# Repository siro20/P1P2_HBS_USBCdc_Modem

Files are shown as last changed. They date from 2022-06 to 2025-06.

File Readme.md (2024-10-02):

# Daikin P1/P2 Raspberry Pi hat

This project is about a Raspberry Pi hat/standalone interface to communicate
over the proprietary Daikin P1/P2 power-line bus.

Instead of a [MAX22088](https://www.analog.com/en/products/max22088.html)
it uses a [Raspberry Pi Pico](https://www.raspberrypi.com/products/raspberry-pi-pico/)
and [LM4871](https://www.ti.com/product/LM4871) audio amplifier as modem.

For more details on P1/P2 bus check out
[https://github.com/Arnold-n/P1P2Serial](https://github.com/Arnold-n/P1P2Serial).

It features:
- Galvanic isolation
- 115200baud ASCII [UART interface](pico/doc/uart.md)
- [3 Status LEDs](pico/doc/leds.md)
- Autonomous mode to emulate "External controller" on address F0h
- Bus idle/busy detection
- Collision detection on TX
- Easy to solder: [no QFN parts, only SOIC-8](kicad/doc/circuits.md)
- Cost around 20€ (PCB + parts)
- Raspberry Pi hat compatible (powered from +5V)
- Micro-USB for standalone mode (powered over USB)

The board can be powered over Micro-USB only and doesn't need a Raspberry Pi
baseboard. The communication then will be done over the virtual USB UART.

    This project is not an offical Daikin product. Use own your own risk!
    It has been tested on a Daikin EJHA04AAV3.

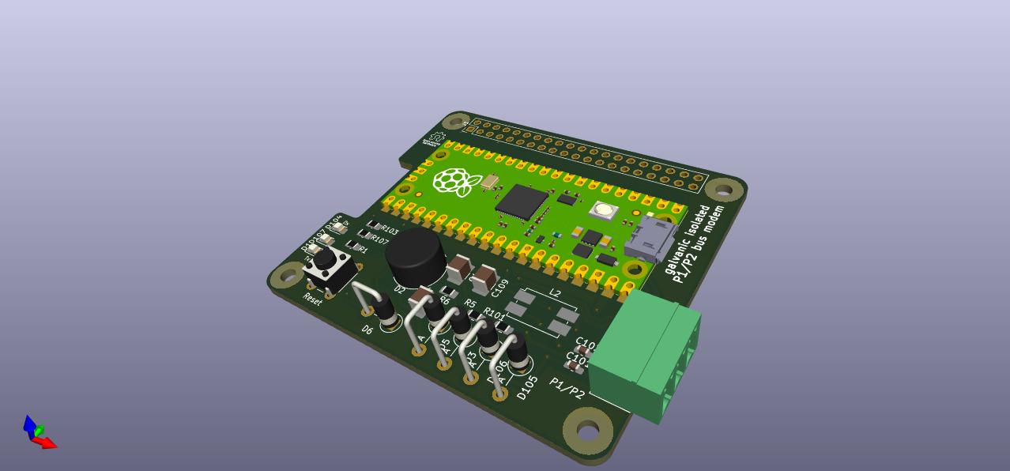
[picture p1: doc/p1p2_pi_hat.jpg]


## Chapters

- [User handbook](doc/handbook.md)
- [The electronics in detail](kicad/doc/circuits.md)
- [Ti LM4871 vs STM TS4990](kicad/doc/clicks.md)
- [Emulating a differential ADC](pico/doc/ADC.md)
- [Protocol used by the UART](pico/doc/uart.md)
- [Decoding the LED status](pico/doc/leds.md)
- [Hardware off-load the P1/P2 encoding using PIO0](pico/doc/Pio0.md)
- [Hardware off-load inversing ADC channel1](pico/doc/Pio1.md)

## Sources

- The hardware can be found here: [kicad](./kicad)
- The software can be found here: [pico](./pico)
- The host software can be found here: [siro20/P1P2decoder](https://github.com/siro20/P1P2decoder)

## The hardware

There are 3 connectors on the Pi hat:
1. Rasperry Pi 40-pin header
   - Provides power
   - Connects to the UART on GPIO14/GPIO15
   - Connects CTS/RTS on GPIO16/GPIO17
   - Signals a bus collision on GPIO22
2. P1/P2 bus connector
   - P1
   - P2
   - Earth
3. Micro USB
   - Allows to update the Pico firmware
   - Powers the board when used in standalone mode
   - Optional when using the 40-pin header

Buttons:
   - A. Reset button
   - B. Boot-mode button

      Hold button B and press button A to enter the Raspberry Pico USB bootloader.

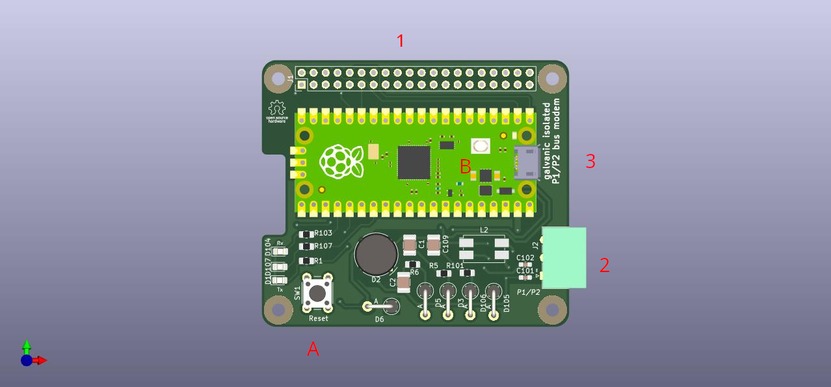
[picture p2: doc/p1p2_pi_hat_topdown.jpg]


## Disclaimer

    THE OPEN SOURCE SOFTWARE/HARDWARE IN THIS PROJECT IS DISTRIBUTED
    IN THE HOPE THAT IT WILL BE USEFUL, BUT WITHOUT ANY WARRANTY, WITHOUT
    EVEN THE IMPLIED WARRANTY OF MERCHANTABILITY OR FITNESS FOR A
    PARTICULAR PURPOSE.

    The "Daikin P1/P2 Raspberry Pi hat" has been designed and tested with
    Daikin's P1/P2 bus. You must not use this project to interface any
    other electrical bus.

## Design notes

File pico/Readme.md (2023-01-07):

# RPI PICO P1/P2 modem source code

This project aims to access the 2-wire interface on Daikin heap pump systems called P1/P2.
It's inspired by [Arnold-n/P1P2Serial](https://github.com/Arnold-n/P1P2Serial), but builds
on a RPI hat using the RPI PICO as P1/P2 modem.

## Design

The modem uses ADC Chan1/Chan2 in round robin mode for RX and PIO0 for TX.

While the TX part needs no CPU cycles (except pushing to the PIO TX FIFO), the
RX path occupies the whole Cortex-M0+ CPU core.

## Build instructions

The code makes use of the [pico-sdk](https://github.com/raspberrypi/pico-sdk).
It's linked as submodule so you need to check it out first:

```
cd pico
git submodule update --init --checkout --recursive
cmake .
make
```

It generates an U2F file in `pico/src/p1p2.uf2` that can be copied to the
USB mass storage devices emulated by the Pico.

### Stats TX
- 16x Oversampling on TX

### Stats RX
- 32x Differential oversampling on RX providing 9bit
- 7-step FIR filter
- Resampler after FIR to 16x Oversampling
- P1/P2 decoder detecting parity, frame and polarity errors

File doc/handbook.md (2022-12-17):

# User handbook

The "Daikin P1/P2 Raspberry Pi hat" can operate in two modes:
1. Standalone
2. RPi hat

In **Standalone mode** the board is powered over USB and the communication
is done over USB CDC.

In **RPi hat mode** the board is connected to a Raspberry Pi using the
40pin connector. You can optionally connect the USB cable, but ito's only
needed for updating the firmware using DCU mode. For normal operation the
USB cable is not required.



### Standalone mode

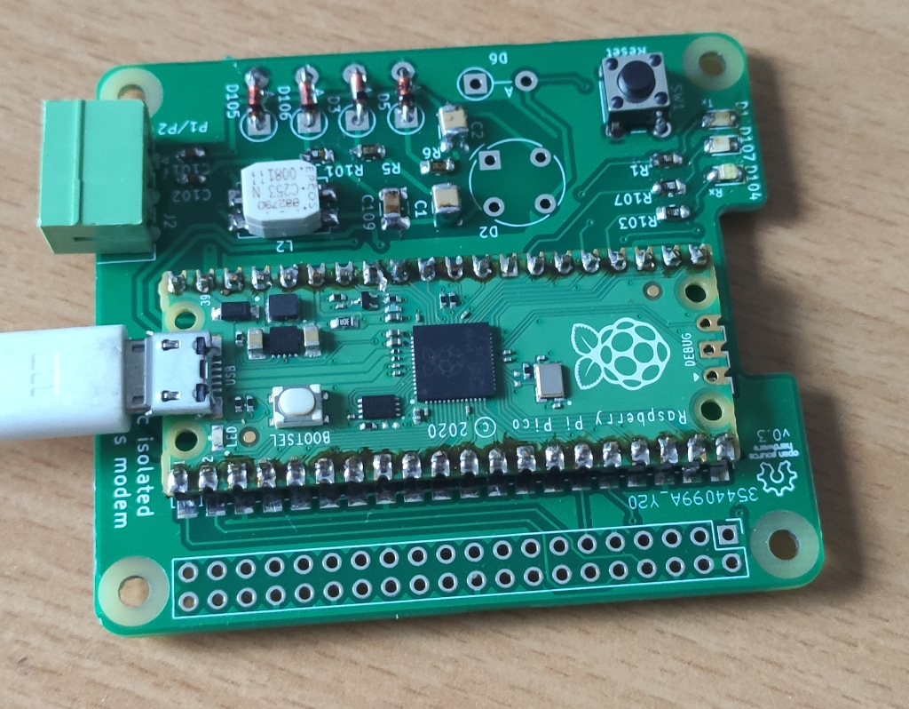
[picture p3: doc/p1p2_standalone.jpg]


Connect P1, P2 (2) and Micro-USB (3) on the RPi Pico.

### RPi hat mode

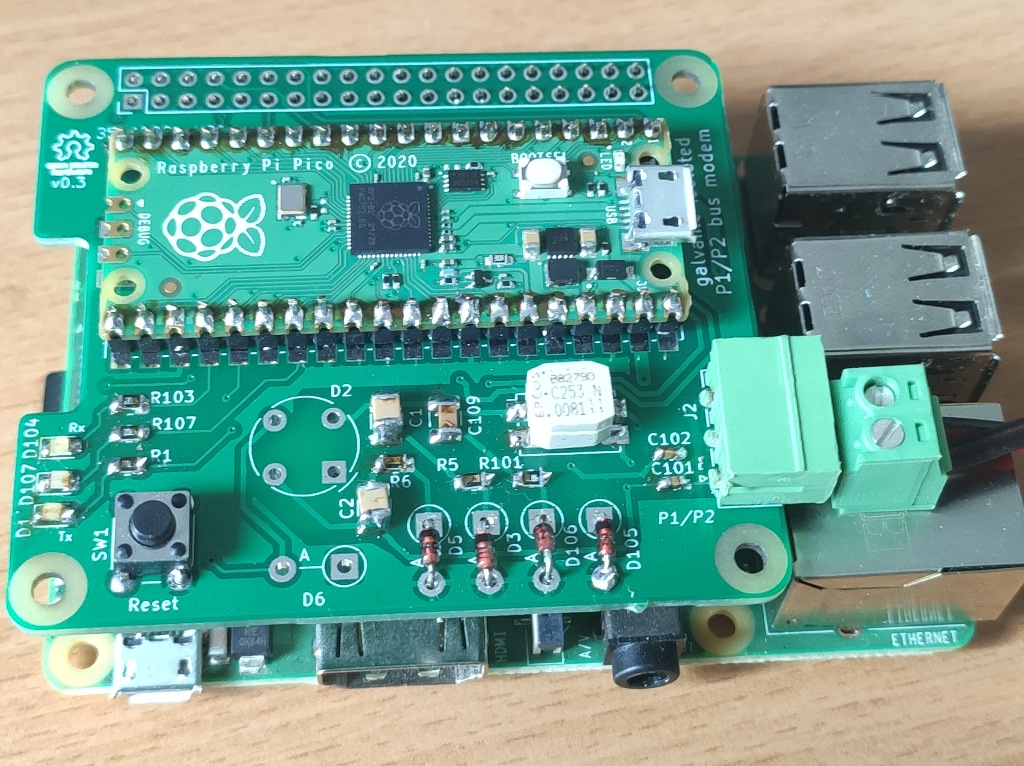
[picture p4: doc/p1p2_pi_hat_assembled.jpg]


Connect P1, P2 (2) and the 40pin pin-header (1).

### Set up RPi UART0

#### Bluetooth module

You must make sure that no other hardware is using the
UART0. On RPI 3 the Bluetooth module is using UART0.
Disable Bluetooth by adding this to `/boot/config.txt`:

    dtoverlay=pi3-disable-bt

#### Login shell
Make also sure that no login shell is running by removing
`console=ttyAMA0` from `/boot/cmdline.txt`

It should look like this (or similar):

    dwc_otg.lpm_enable=0 console=tty1 root=/dev/mmcblk0p2 rootfstype=ext4 elevator=deadline rootwait

and not like this:

    dwc_otg.lpm_enable=0 console=ttyAMA0,115200 kgdboc=ttyAMA0,115200 console=tty1 root=/dev/mmcblk0p2 rootfstype=ext4 elevator=deadline rootwait

## Flashing new firmware on the Pico

You need to connect the Micro-USB cable to use the USB mass storage
firmware update method.

1. Press the reset button (A) down and hold it.
2. Press the BOOTSEL button (B) on the Pico and hold it.
3. Release the reset button (A).
4. Release the BOOTSEL button (B).

The Pico will enter USB DFU mode.

Drag and Drop the new firmware onto the USB mass storage drive.

## Handling the data

The "Daikin P1/P2 Raspberry Pi hat" provides the captured packets in
an ASCII based hexdump. 

More details can be found here: [Protocol used by the UART](../pico/doc/uart.md)

## Status LEDs

The board has 3 status LEDs showing the curren operating state.
Please refer to [Decoding the LED status](../pico/doc/leds.md) for details.

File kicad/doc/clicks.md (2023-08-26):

# Audio IC shutdown and wakeup

The audio amplifier IC, as descibed in the [circuits section](circuits.md),
is shut down on RX and only enabled when something needs to be transmitted.

This also ensure high impedance seen on the remote bus transmitter. It's
critical that the shutdown and power on doesn't cause huge differential
voltage spikes. Spikes could be interpreted by the remote as start of
new packet.

## Ti LM4871

The Ti LM4871 has a startup time of 15msec. During the startup time there's
a huge distortion at the output, commonly refered to as "clicks" or "pops".

The following sample shows the traffic on the P1/P2 bus, as well as the
power off and power on behaviour.
While power off is OK, as the differential
voltage is 0, the turn on click is unacceptable.



**Experiments showed that the output drives at full power with less than 4 Ohms
impedance. An external circuit isn't capable of keeping the differential
voltage low.**

## STM TS4990

The STM TS4990 is a pin compatible audio amplifier IC that advertises the
"Near-zero pop and click" feature. The STM TS4990 has a startup time of 32
msec.

The following sample shows the traffic on the P1/P2 bus, as well as the
power off and power on behaviour



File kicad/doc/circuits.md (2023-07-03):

# The analog part

Instead of using the [MAX22088](https://datasheets.maximintegrated.com/en/ds/MAX22088.pdf),
which only ships as QFN package, this project uses a [LM4871](https://www.ti.com/lit/ds/symlink/lm4871.pdf)
as transmitter and a [Raspberry Pi Pico](https://www.raspberrypi.com/products/raspberry-pi-pico/)
as receiver.

*Warning:* Totally overengineered project ahead!

## Ti LM4871 vs STM TS4990

In version `v0.1` and `v0.2` the *Ti LM4871* has been used.

Starting from version `v0.3` the STM TS4990 is being used as
pin-compatible replacement.

See [Ti LM4871 vs STM TS4990](clicks.md) for details.

## The transmitter

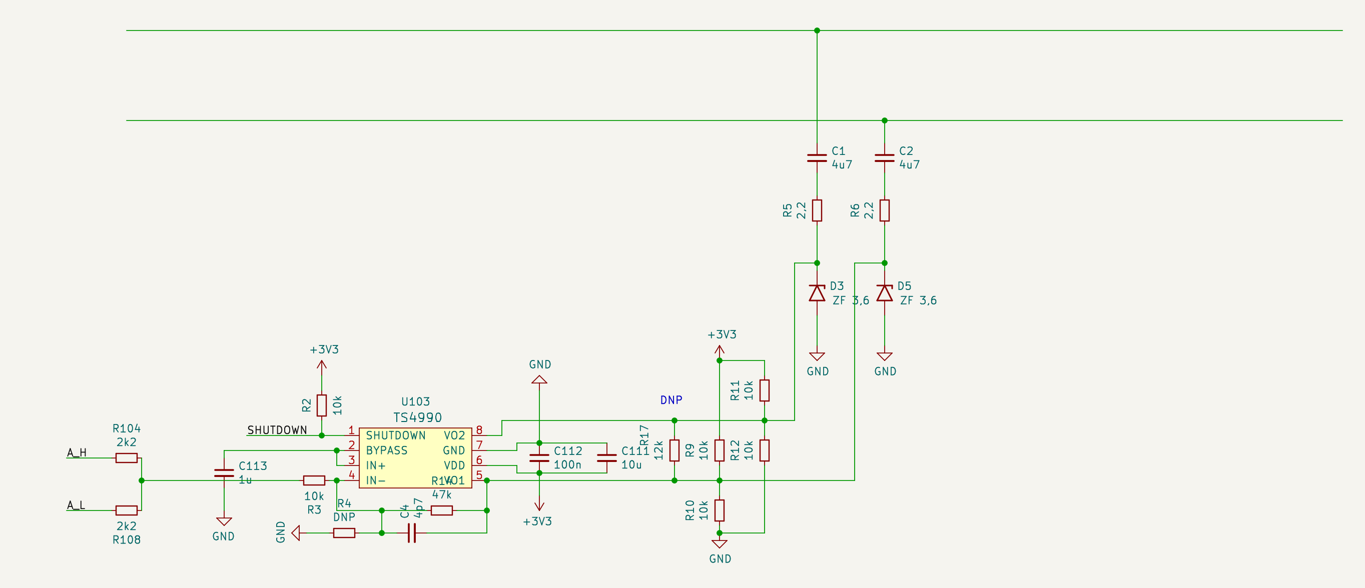
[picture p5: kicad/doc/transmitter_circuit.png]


The [LM4871](https://www.ti.com/lit/ds/symlink/lm4871.pdf) is and dual
ouput 3W audio amplifier and the circuit around it is following the
design guidelines.
The input is an analog signal generated by a 3 level signal from GPIO
`A_H` and `A_L`. The resulting analog signal has
one of the following levels:
- 3.30V
- 1.65V
- 0.00V

The Z-Diodes `D3` and `D5` protect the device from voltage spikes that
could be introduced on the long P1/P2 lines.

`R5` and `R6` limit the output impedance to more than 4Ohms.

`R11`, `R12`, `R10` and `R9` pull the lines to idle position when the LM4871 is in
shutdown mode. They also provide a minimum load of 10KOhms if the P1/P2 bus is
not connected. **The LM4871 tend to oscillate at several Mhz without a load.
The datasheet recommends 2KOhms as minimum load!**

**`C4` prevents oscillations that can happen if the gain is too small.
Using 4.7pF and a gain of 5 seem to prevent most oscillations.**

The [LM4871](https://www.ti.com/lit/ds/symlink/lm4871.pdf) is able to
drive 0.5Watts at 3.3V.

### Measured results



The [LM4871](https://www.ti.com/lit/ds/symlink/lm4871.pdf) can drive a 3.0V
amplitude signal from a 3.3V supply. Due to the dual-output the generated
differential signal has a level of +/- 3.0V.

## The receiver

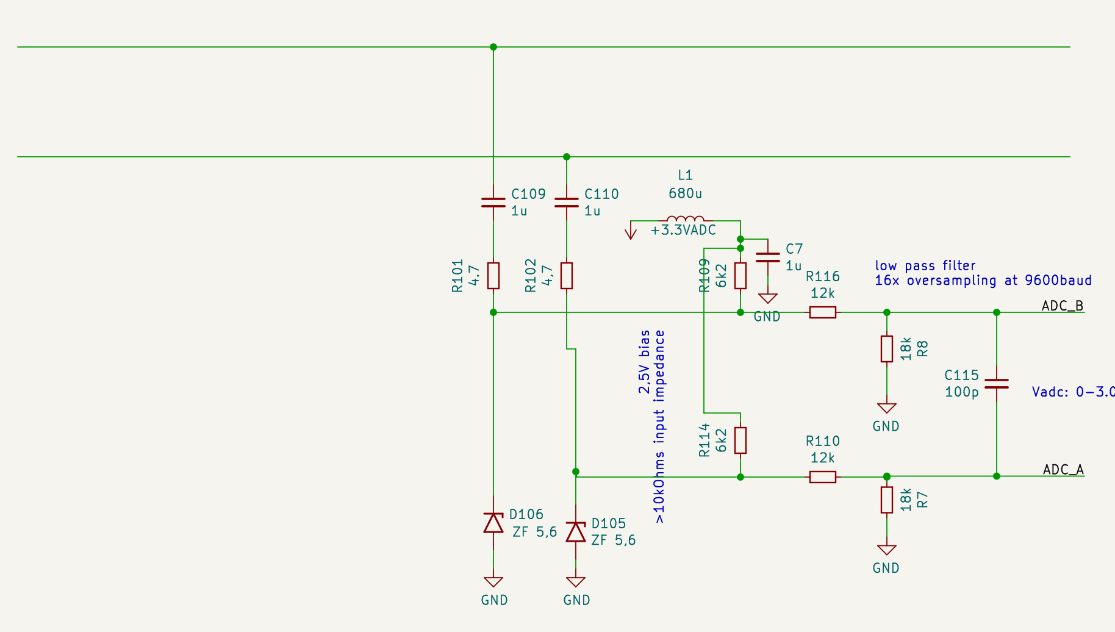
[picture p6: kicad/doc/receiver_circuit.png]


The Z-Diodes `D106` and `D105` protect the device from voltage spikes that
could be introduced on the long P1/P2 lines.

`R109`, `R116` and `R8` are providing a bias voltage of 2,5V (when driven by 3.0V ADC voltage)
and they divide the signal amplitude by 1.66.

`R114`, `R110` and `R7` are providing a bias voltage of 2,5V (when driven by 3.0V ADC voltage)
and they divide the signal amplitude by 1.66.

The total impedance of `R109`, `R116`, `R8`, `R114`, `R110` and `R7` is greater than 10KOhms.

`C115` acts a low pass filter.

`ADC_A` and `ADC_B` should be connected to a differential ADC. In this case it's
a RPi pico using ADC0 and ADC1.

### Measured results

The signal has been measured on the Pico ADC behind the AC coupling capacitors and voltage
divider:



The voltage on the ADC has an amplitude of `1.73V`. Mutliplied with the voltage
dividor reciprocal gain this give a `2.87V` amplitude after AC coupling.

When connected to the P1/P2 bus the amplitude is a actually a bit lower: `2.5V`

It is suffcient to be detected by the remote P1/P2 transceiver circuit.
The P1/P2 remote transceiver drives a `5V` amplitude on the bus.

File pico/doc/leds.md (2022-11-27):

# LED manager
The pico drives 3 LEDs to signal its current operating state.
There are
* TX LED
* RX LED
* Power LED

Every LED can be one of [OFF, ON, Slowly BLINKING, Fast BLINKING].

## Decoding LED states

**Board is idle:**
```
RX  off
PWR on
TX  off
```

**Board is RXing data:**
```
RX  slowly blinking
PWR on
TX  off
```

**Board is TXing data: (impossible state)**

(The board should always RX data when it's TXing.)
```
RX  off
PWR on
TX  slowly blinking
```

**Board is RX/TXing data:**
```
RX  slowly blinking
PWR on
TX  slowly blinking
```

**Board has RX data with parity error:**
```
RX  fast blinking
PWR fast blinking
TX  off
```

**Board transmitted data, but a bus collision happened:**
```
RX  off
PWR fast blinking
TX  fast blinking
```

**Internal error:**

ADC underrun, FIFO overrun, Line busy for too long, UART TX buffer overflow, ...
```
RX  off
PWR fast blinking
TX  off
```

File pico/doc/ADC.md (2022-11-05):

# ADC documentation

The ADC uses two channels to sample the differential P1/P2 bus.
Together with some glue code this emulates a phase correct differential
ADC with a delay of one sample.

## Overview

The P1/P2 differential signal is captured by two ADC channels (Channel0 + Channel1)
in round robin mode.

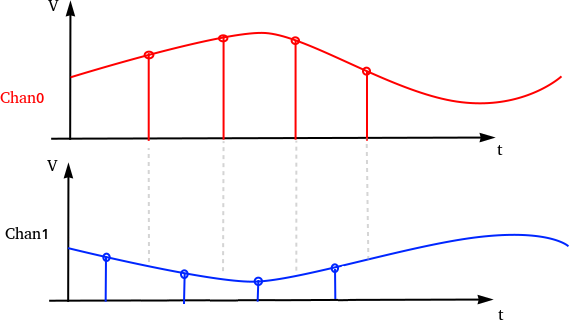
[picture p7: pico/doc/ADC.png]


Channel0 as shown in red and Channel1 as shown in blue is captured in round robin
mode.

To make sure the signal is phase correct the captured data is delayed by one sample.
For every ADC sample the average of the current sample and the last sample of the
same channel is being calculated to get the voltage at sampling the "other" channel.

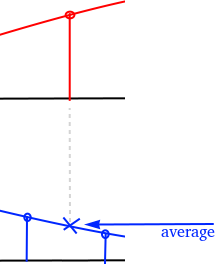
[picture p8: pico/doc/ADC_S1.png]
First channel averaging.
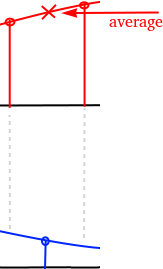
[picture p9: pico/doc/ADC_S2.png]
Second channel averaging.
 

The code makes use of the DMA subsystem and ring buffers to store ADC samples for
later processing.

## The code

```C
	adc_init();

	// Make sure :GPIOs are high-impedance, no pullups etc
	adc_gpio_init(26);
	adc_gpio_init(27);

	// Select ADC input 0 (GPIO26)
	adc_select_input(0);

	adc_fifo_setup(
		true,    // Write each completed conversion to the sample FIFO
		true,    // Enable DMA data request (DREQ)
		1,       // DREQ (and IRQ) asserted when at least 1 sample present
		false,   // We won't see the ERR bit because of 8 bit reads; disable.
		true     // Shift each sample to 8 bits when pushing to FIFO
	);

	adc_set_clkdiv(48000000 / (UART_BAUD_RATE * ADC_OVERSAMPLING_RATE));
	adc_set_round_robin(0x3); // Sample ADC0 + ADC1 in RR
```

Initialize the ADC and the first two channels. Configures the channels in round robin mode.

```C
	// set wrap boundary. This is why we needed alignment!
	channel_config_set_ring(&c, true, 9); // 1 << 9 byte boundary on write ptr

	dma_channel_configure(this->channel2, &c,
		this->data,     // dst
		twos_complement_dma_rx_reg(this->pio, this->sm),  // src
		this->tc,       // transfer count
		true            // start immediately
	);
```
Transfers ADC samples to a ring buffer in SRAM.

```C
	tc_hw = dma_channel_hw_addr(this->channel2)->transfer_count;
	// Compare transfer count with internal shadow register
	if (this->tc == tc_hw)
		return false;

	// Got data!
	this->tc--;
```
The CPU then polls for data availability in the ring buffer by comparing the
transfer_count with the shadow buffer `tc`. If a difference exists the DMA
hardware has transfered more data to the SRAM ring buffer.

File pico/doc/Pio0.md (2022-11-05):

# PIO0 documentation

PIO0 is used as P1/P2 UART. It does CRC calculation, bit stuffing and AMI coding in hardware and thus offloads the
CPU. IRQ0 is used as busy indicator.

## Overview

The PIO program reads in 8bit data samples and transmits them using two GPIOs. The GPIOs are connected
to two equal sized resistors, encoding 0b00 as 0V, 0b11 as 3.3V and 0b10 as 1.65V.
This is enough for an AMI signal and can then be driven on the P1/P2 bus.



## The glue code

```C
    // Route pins to PIO
    pio_gpio_init(pio, pin_tx);
    pio_gpio_init(pio, pin_tx+1);

    // Disable pull on pins
    gpio_disable_pulls(pin_tx);
    gpio_disable_pulls(pin_tx+1);

    gpio_set_slew_rate(pin_tx, GPIO_SLEW_RATE_FAST);
    gpio_set_slew_rate(pin_tx+1, GPIO_SLEW_RATE_FAST);

    // Set pins to output
    pio_sm_set_consecutive_pindirs(pio, sm, pin_tx, 2, true/*output*/);

    pio_sm_config c = p1p2_uart_tx_program_get_default_config(offset);

    // OUT shifts to left, LSB first, no autopull
    sm_config_set_out_shift(&c, true, false, 8);

    // Set both pins as sideset pins
    sm_config_set_sideset_pins(&c, pin_tx);
    sm_config_set_sideset(&c, 2, false, false);
```
Configure GPIOs, set shift direction and set sideset pins.

```C
    // We only need TX, so get an 8-deep FIFO!
    sm_config_set_fifo_join(&c, PIO_FIFO_JOIN_TX);
```
Disable RX FIFO and append it to the TX FIFO.

```
    // SM transmits 1 bit per 16 execution cycles.
    float div = (float)clock_get_hz(clk_sys) / (16 * baud);
    sm_config_set_clkdiv(&c, div);
```
Set the clock rate to 16x oversampling. As the maximum sideset delay is 7 (+1 for the instruction),
every bit must be encoded by two or more instruction.

```C
    // Clear IRQ flag before starting, and make sure flag doesn't actually
    // assert a system-level interrupt (we're using it as a status flag)
    pio_set_irq0_source_enabled(pio, isr, false);
    pio_set_irq1_source_enabled(pio, isr, false);
    pio_interrupt_clear(pio, sm);
```
Make sure to disable the interrupts. The IRQ bits are used to indicate that the
UART is busy.

```C
    pio_sm_init(pio, sm, offset, &c);
    pio_sm_set_enabled(pio, sm, true);
}

static inline void p1p2_uart_tx(PIO pio, uint sm, const uint8_t data) {
	pio_sm_put(pio, sm, data);
}
```
Start the PIO state machine. Also provide an better name for the TX method.
## The source

```C
.program p1p2_uart_tx

.side_set 2	; The two pins for an analog voltage but using two resistors

.define LEVEL_ONE       2 ; Analog voltage = 0.5 Vcc
.define LEVEL_IDLE      1 ; Same as ONE, but swapped (will be visible on oscilloscope)
.define LEVEL_ZERO_UP   3 ; Analog voltage = Vcc
.define LEVEL_ZERO_DOWN 0 ; Analog voltage = GND

```
Define the number of side-set bits. This reduces the possible side delay bits (maximum 7).
Defines the AMI levels driven on the sideset pins.

```C
public start:
next_byte:
    irq clear 0          side LEVEL_IDLE            ; clear IRQ while blocked
    pull block           side LEVEL_IDLE            ; send data bits until OSR empty

    ; send start bit
    irq set 0            side LEVEL_ZERO_UP    [7]  ; set IRQ while transmitting
    nop                  side LEVEL_IDLE       [5]  ; discard 24 bits to transmit 8 bits only

loop_odd:
    out y, 1             side LEVEL_IDLE            ; get next data bit 
    jmp !y, send_0_odd   side LEVEL_IDLE
send_1_odd:
    nop                  side LEVEL_ONE        [7]
    nop                  side LEVEL_IDLE       [3]
    jmp loop_end_odd     side LEVEL_IDLE            ; keep parity

send_0_odd:
    nop                  side LEVEL_ZERO_DOWN  [7]
    nop                  side LEVEL_IDLE       [3]
    jmp loop_end_even    side LEVEL_IDLE            ; toggle parity 

loop_even:
    out y, 1             side LEVEL_IDLE            ; get next data bit
    jmp !y, send_0_even  side LEVEL_IDLE
send_1_even:
    nop                  side LEVEL_ONE        [7]
    nop                  side LEVEL_IDLE       [3]
    jmp loop_end_even    side LEVEL_IDLE            ; keep parity
send_0_even:
    nop                  side LEVEL_ZERO_UP    [7]
    nop                  side LEVEL_IDLE       [3]
    jmp loop_end_odd     side LEVEL_IDLE            ; toggle parity 

loop_end_odd:
    jmp !osre, loop_odd  side LEVEL_IDLE
    nop                  side LEVEL_IDLE       [1]  ; finish idle phase of last bit
    nop                  side LEVEL_ZERO_DOWN  [7]  ; send '0' to make parity even
    nop                  side LEVEL_IDLE       [7]

    nop                  side LEVEL_ONE        [7]  ; send '1' as stop bit
    jmp next_byte        side LEVEL_IDLE       [4]  ; idle phase of stop bit, then jump

loop_end_even:
    jmp !osre, loop_even side LEVEL_IDLE
    nop                  side LEVEL_IDLE       [1]  ; finish idle phase of last bit
    nop                  side LEVEL_ONE        [7]  ; send '1' to keep parity even
    nop                  side LEVEL_IDLE       [7]

    nop                  side LEVEL_ONE        [7]  ; send '1' as stop bit
    jmp next_byte        side LEVEL_IDLE       [4]  ; idle phase of stop bit, then jump
```

The GPIOs are driven using the `side XXX` instruction as part of the regular programm flow.

Parity is calculated by jumping between `loop_end_even` and `loop_end_odd`. At the end of
data transmission this can be used to transmit the correct parity bit.
Usually parity is calculated on the '1' bit, but here it uses the '0' bit and thus can drive
the AMI code at the same time. On every '0' parity flips and AMI code flips as well.

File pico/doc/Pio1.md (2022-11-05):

# PIO1 documentation

PIO1 is connected to the DMA and converts the ADC sampled data for easier CPU
processing. This is not necessary, but reduces the CPU load as the summation
of the two ADC phases is essential for a differential ADC and thus is the most
often called routine on the chip.

## Overview

The PIO program reads in 8bit data samples (uint8_t) and creates a 16bit signed output data sample (int16_t).
The first data sample is inverted using the twos complement algorithm.
Every second data sample is not in inverted and just converted to 16bit.

By adding the two signed data samples the differential signal can be calculated.



## The glue code

The PIO programm is loaded into PIO1 SM0 by the code ...

```C
	PIO pio = pio1;
	uint sm = 0;
	uint offset = pio_add_program(this->pio, &twos_complement_program);
	twos_complement_program_init(this->pio, this->sm, offset);
```

... and connected by two DMA channels. The first transfers data from ADC FIFO to the PIO TX FIFO.
```C
		// Get a free channel, panic() if there are none
		channel = dma_claim_unused_channel(true);

		dma_channel_config c = dma_channel_get_default_config(channel);
		// 8 bit transfers
		channel_config_set_transfer_data_size(&c, DMA_SIZE_8);
		//  don't increment read and write address
		channel_config_set_read_increment(&c, false);
		channel_config_set_write_increment(&c, false);

		channel_config_set_high_priority(&c, true);

		// Pace transfers based on availability of ADC samples
		channel_config_set_dreq(&c, DREQ_ADC);

		dma_channel_configure(tchannel, &c,
			twos_complement_dma_tx_reg(pio, sm),  // dst
			&adc_hw->fifo,  // src
			0xffffffff,     // transfer count
			true            // start immediately
		);
```

The second places data from PIO FIFO on some destination:
```C
		// Get a free channel, panic() if there are none
		int channel2 = dma_claim_unused_channel(true);
	
		dma_channel_config c = dma_channel_get_default_config(channel2);
		// 16 bit transfers
		channel_config_set_transfer_data_size(&c, DMA_SIZE_16);

		// increment the write adddress, don't increment read address
		channel_config_set_read_increment(&c, false);
		channel_config_set_write_increment(&c, true);

		// Pace transfers based on availability of PIO samples
		channel_config_set_dreq(&c, pio_get_dreq(pio, sm, false));

		// Set destination .....
```

## The source

The PIO source to create the twos complement. As 8bit input data are provided the data
is converted to 16bit to not lose 1bit precision. Data is shifted out LSB first.

```asm
.program twos_complement

entry:
	; x = 7
	set x, 7
	; Get data from output FIFO
	pull block
```
The program prepares scratch register `x` with the number of iterations and blocks until data arrives in the input FIFO.

```asm
next_0: ; 4 instructions per bit, +1/+2 on last bit
	; Get one bit from OSR
	out y, 1
	; Shift into ISR
	in y, 1
```
Shift LSB from OSR to ISR.

```asm
	; x--
	jmp x-- not_done_yet
	; At this point all bits have been shifted in
	; x = 0xff due to previous decrement
	; if (y > 0) jmp done
	jmp y-- done
	; x = 0
	set x, 0
	; jmp done
	jmp done
not_done_yet:
	; if (y == 0) jmp next_0; else next_invert
	jmp !y next_0
```
Decrement x and test if done. If not done it jumps to `not_done_yet` and continues the loop. If the bit was `1` it does not jump to `next_0`, but continues below.

If done check of the MSB needs to be `0b11111111`or `0b00000000` and jump to `done`.

```asm
; invert remaining bits
	mov osr, ~osr
next_invert: ; 3 instructions per bit, +1 on last bit
	; Get one bit from OSR
	out y, 1
	; Shift into ISR
	in y, 1
	; if (x--) jmp next_invert
	jmp x-- next_invert
	; x = 0xff due to previous decrement
```
Invert the remaining bits in the `OSR` and shift them all from OSR to ISR. Decrement x and test if done.

```asm
done:
	; push high byte
	in x, 8

	; shift in 16 0s
	in null, 16
	; Push to input FIFO
	push block
```
`done` is always entered after 8 bits has been shifted into `ISR`. Shift in the high bytes (they don't care as we only need 16bit).

```asm
	; Get second byte and don't do any modification
	pull block
	out y, 8
	in y, 8
	in null, 24
	push block

	jmp entry
```
The second data sample is not inverted and just converted to 16bit.

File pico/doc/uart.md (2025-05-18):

# UART data

The packets received on the P1/P2 bus are decoded and send to the
USB CDC and hardware UART on the RPi 40 pin connector.

1. The baud rate is 115200 8N1 no parity
2. The data is tranfered as ASCII and hex encoded.
3. The hex encoding might have whitespace between the hex characters
4. Every line contains one paket.
5. Every line is terminated with '\n'
6. Everything after `#` or `;` must be ignored
7. On error a status is send, separated by `#`
   - The status indicates which kind of error happened
   - Since an error happened the data is likely corrupted.
8. Lines starting with `#` or `;` must be ignored

## Fields

Every message has the following format:

   Hex Data [ # Status ]

## Status

A zero status byte signals no error. Zero status is never transmitted.
On non zero status byte signals an error has happened.
One of the following errors are signaled:

* 1 : STATUS_ERR_BUS_COLLISION
  *  Did not RX the exact same data that was TXed
* 2 : STATUS_ERR_OVERFLOW
  * A buffer overflowed
* 3 : STATUS_ERR_PARITY
  * Parity error
* 4 : STATUS_ERR_NO_FRAMING
  * Did not detect line idle within timeout. Just receiving noise?

## Examples

**Example 1:**

`AB CD DE EF`

* Status: `00` - OK
* Data: `ABCDDEEF`

**Example 2:**

`CDefabcd # 01`

* Status: `1`
* Data: `CDEFABCD`

## Captured data

Captured data from bus:

    00001001810100000000150040000008000018004030006d
    400010018021013000180015005a00000000000040000073
    0000111098000000000000cf
    40001120ae2f780c8023141f90249810980c8100000000db
    000012c002132f1701040000000000413403d8
    40001240400000006300000000007f010400000000000042
    00001300005004
    4000133000035200000f00000075b2f6c1000004
    0000142d0012002d000700000000000000001f
    4000142d0012002d000700000000000000001d00250052
    00001500002300051459
    40001500000a8000000f000010
    000016000032140000000000000000000000005c
    4000160000000000000000e106
    00f0300100000002010000000000000000ec
    40f03000000000010000010000000000007a
    00f031000000018005170104132f3515
    00f035240000250000260000270001280000290000ee
    00f03577010f780100790100ffffffffffffffffff17
    00f03614005e01ffffffffffffffffffffffffffffffffd8
    00f038ffffffffffffffffffffffffffffffffffff8a
    00001001810100000000150040000008000018004030006d
    400010018021013000180015005a00000000000040000073

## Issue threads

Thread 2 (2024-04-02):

Part number for bridge rectifier

arc12, 2024-04-02:
Hi -
I cannot see a part number for the bridge rectifier; the KiCAD output and sch file just seem to have the placeholder "D_Bridge_+A-A" (is that a KiCAD generic part?).
Maybe I misunderstand or missed something...
What part number for this device, or specifications ??

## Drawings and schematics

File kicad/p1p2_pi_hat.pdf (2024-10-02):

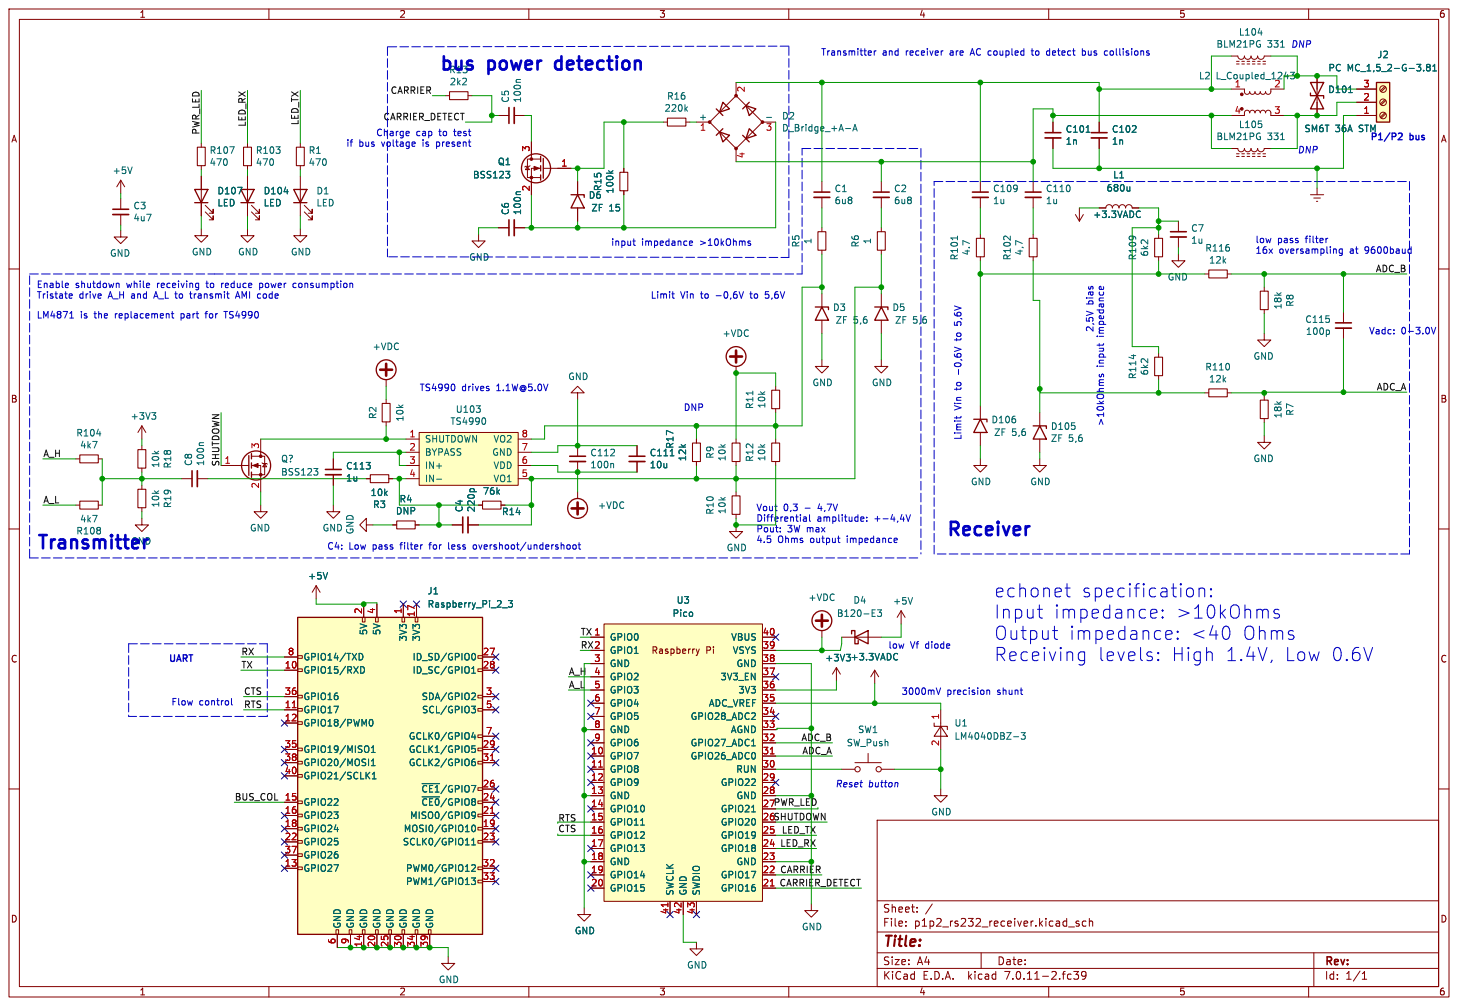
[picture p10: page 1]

if bus voltage is present UART

Pout: 3W max 4.5 Ohms output impedance

Id: 1/1 Title: File: p1p2_rs232_receiver.kicad_sch Sheet: / +VDC

Receiving levels: High 1.4V, Low 0.6V

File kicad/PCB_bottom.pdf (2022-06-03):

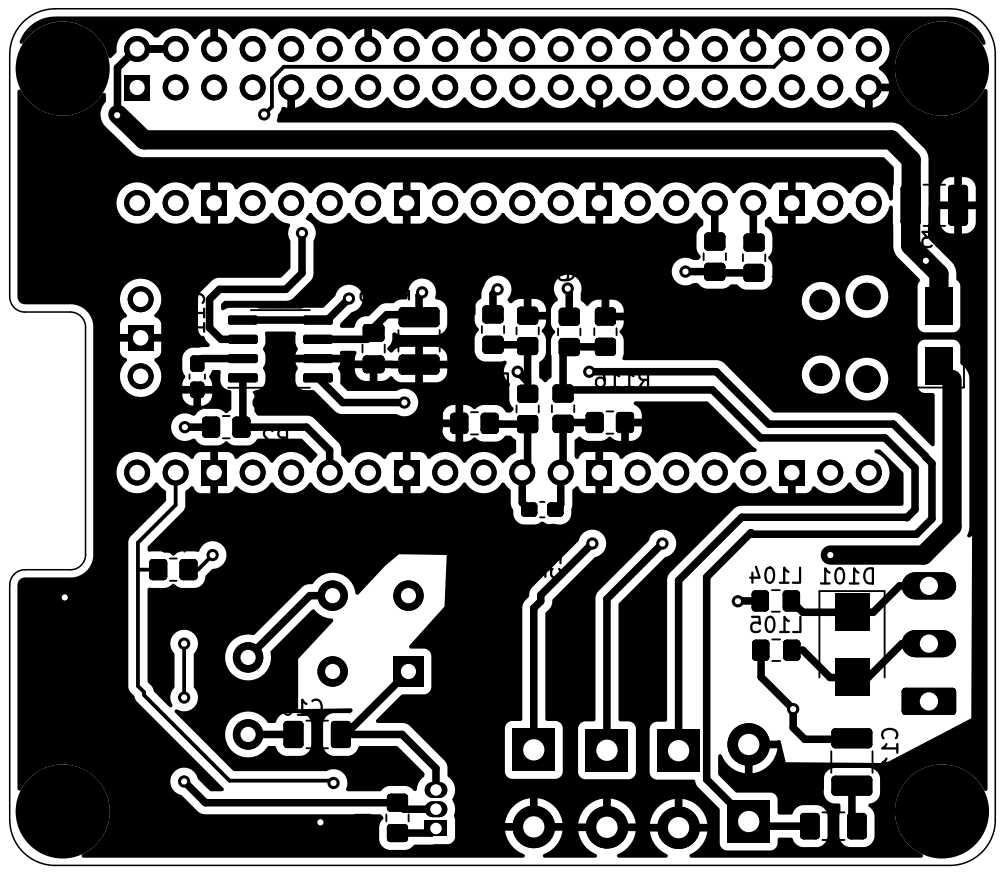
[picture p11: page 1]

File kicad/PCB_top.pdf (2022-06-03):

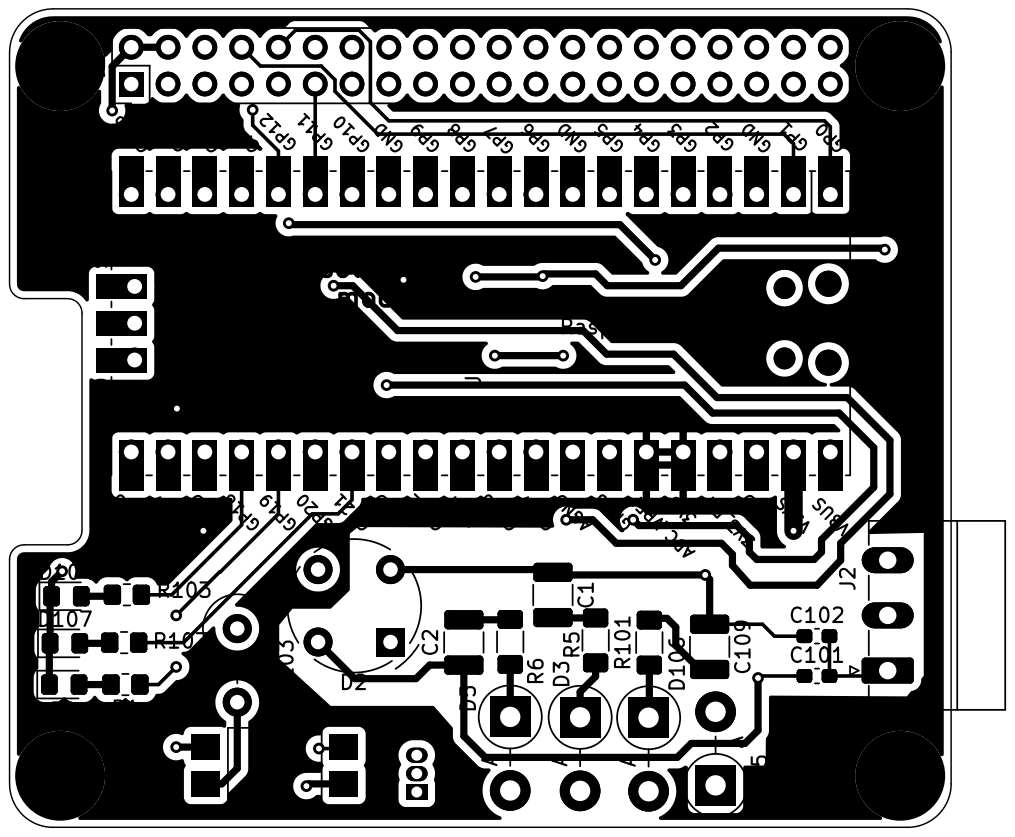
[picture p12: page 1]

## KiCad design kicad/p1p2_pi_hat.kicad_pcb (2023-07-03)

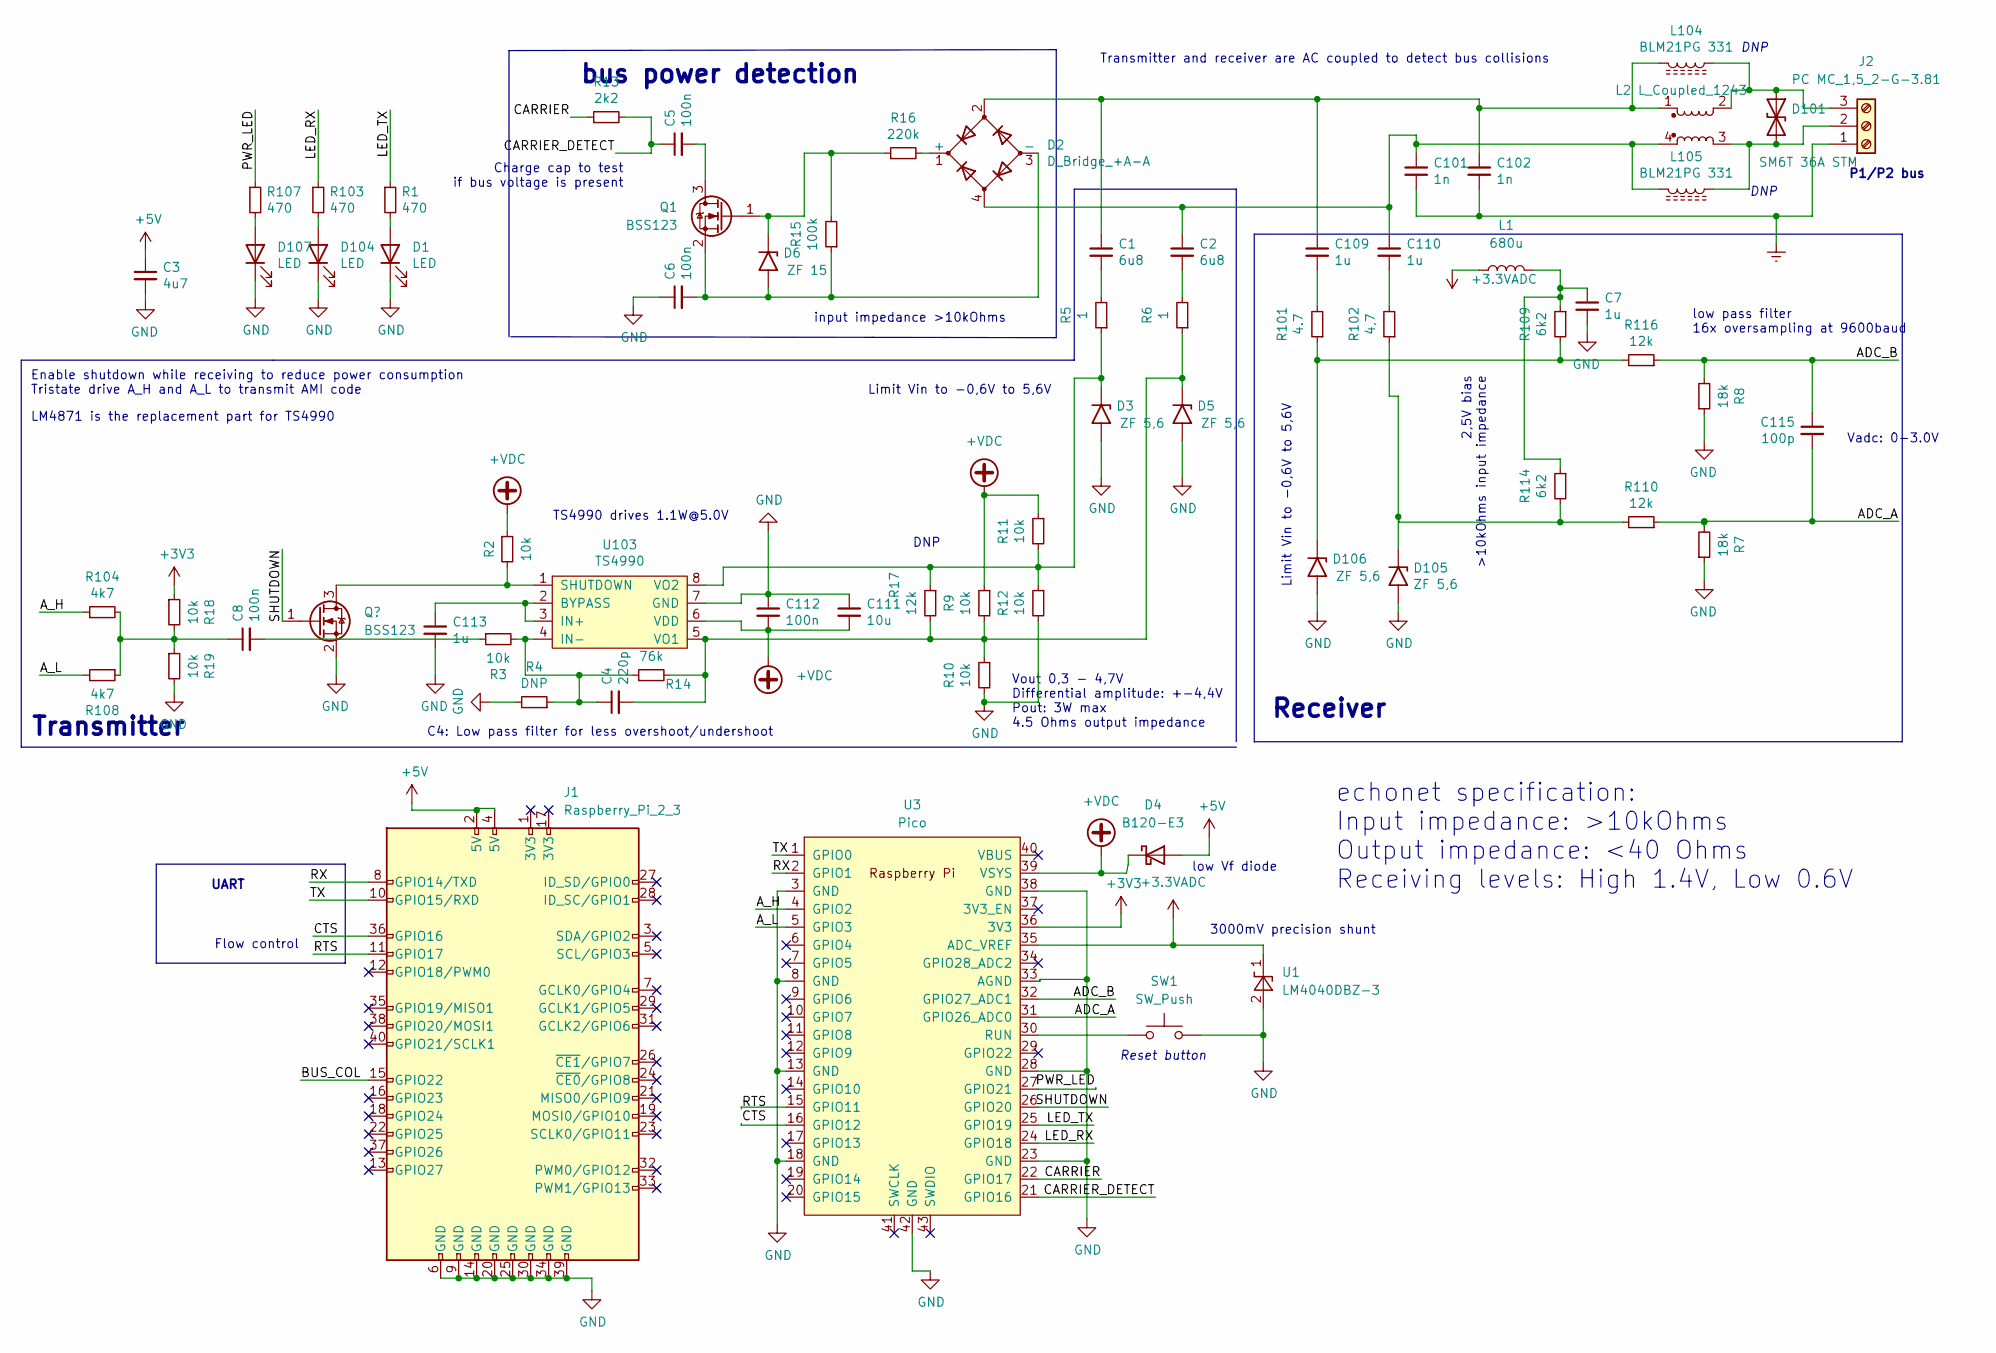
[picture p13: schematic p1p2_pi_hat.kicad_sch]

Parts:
C1, C2: 6u8; C_1210_3225Metric_Pad1.33x2.70mm_HandSolder
C3: 4u7; C_1210_3225Metric_Pad1.33x2.70mm_HandSolder
C4: 220p; C_0805_2012Metric_Pad1.18x1.45mm_HandSolder
C5, C6, C8, C112: 100n; C_0805_2012Metric_Pad1.18x1.45mm_HandSolder
C7, C109, C110: 1u; C_1210_3225Metric_Pad1.33x2.70mm_HandSolder
C101, C102: 1n; C_0603_1608Metric_Pad1.08x0.95mm_HandSolder
C111: 10u; C_1210_3225Metric_Pad1.33x2.70mm_HandSolder
C113: 1u; C_0603_1608Metric_Pad1.08x0.95mm_HandSolder
C115: 100p; C_0603_1608Metric_Pad1.08x0.95mm_HandSolder
D1, D104, D107: LED; LED_0805_2012Metric_Pad1.15x1.40mm_HandSolder
D2: D_Bridge_+A-A; Diode_Bridge_Round_D9.0mm
D3, D5, D105, D106: ZF 5,6; D_DO-41_SOD81_P5.08mm_Vertical_AnodeUp
D4: B120-E3; D_SMA
D6: ZF 15; D_DO-41_SOD81_P5.08mm_Vertical_AnodeUp
D101: SM6T 36A STM; D_SMB
J1: Raspberry_Pi_2_3; PinHeader_2x20_P2.54mm_Vertical
J2: PC MC_1,5_2-G-3.81; PhoenixContact_MC_1,5_3-G-3.81_1x03_P3.81mm_Horizontal
L1: 680u; L_1210_3225Metric_Pad1.42x2.65mm_HandSolder
L2: L_Coupled_1243; L_CommonMode_TDK_B82790C0
L104, L105: BLM21PG 331; L_0805_2012Metric_Pad1.15x1.40mm_HandSolder
Q1: BSS123; SOT-23
R1, R103, R107: 470; R_0805_2012Metric_Pad1.20x1.40mm_HandSolder
R2, R3, R9, R10, R11, R12, R18, R19: 10k; R_0805_2012Metric_Pad1.20x1.40mm_HandSolder
R4: DNP; R_0805_2012Metric_Pad1.20x1.40mm_HandSolder
R5, R6: 1; R_0805_2012Metric_Pad1.20x1.40mm_HandSolder
R7, R8: 18k; R_0805_2012Metric_Pad1.20x1.40mm_HandSolder
R13: 2k2; R_0805_2012Metric_Pad1.20x1.40mm_HandSolder
R14: 76k; R_0805_2012Metric_Pad1.20x1.40mm_HandSolder
R15: 100k; R_0805_2012Metric_Pad1.20x1.40mm_HandSolder
R16: 220k; R_0805_2012Metric_Pad1.20x1.40mm_HandSolder
R17, R110, R116: 12k; R_0805_2012Metric_Pad1.20x1.40mm_HandSolder
R101: 4.7; R_0805_2012Metric_Pad1.20x1.40mm_HandSolder
R102: 4,7; R_0805_2012Metric_Pad1.20x1.40mm_HandSolder
R104, R108: 4k7; R_0805_2012Metric_Pad1.20x1.40mm_HandSolder
R109, R114: 6k2; R_0805_2012Metric_Pad1.20x1.40mm_HandSolder
SW1: SW_Push; SW_PUSH_6mm_H5mm
U1: LM4040DBZ-3; SOT-23
U3: Pico; RPi_Pico_SMD_TH
U103: TS4990; SOIC-8_3.9x4.9mm_P1.27mm

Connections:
+3.3VADC: L1.1, U1.1 (K), U3.35 (ADC_VREF)
+3V3: R18.1, U3.36 (3V3)
+5V: C3.1, D4.2 (A), J1.2 (5V), J1.4 (5V)
+VDC: C111.2, C112.2, D4.1 (K), R2.1, R9.1, R11.1, U3.39 (VSYS), U103.6 (VDD)
/ADC_A: C115.2, R7.2, R110.1, U3.31 (GPIO26_ADC0)
/ADC_B: C115.1, R8.2, R116.1, U3.32 (GPIO27_ADC1)
/A_H: R104.1, U3.4 (GPIO2)
/A_L: R108.2, U3.5 (GPIO3)
/BUS_COL: J1.15 (GPIO22)
/CARRIER: R13.1, U3.22 (GPIO17)
/CARRIER_DETECT: C5.1, R13.2, U3.21 (GPIO16)
/CTS: J1.36 (GPIO16), U3.16 (GPIO12)
/LED_RX: R103.1, U3.24 (GPIO18)
/LED_TX: R1.1, U3.25 (GPIO19)
/PWR_LED: R107.1, U3.27 (GPIO21)
/RTS: J1.11 (GPIO17), U3.15 (GPIO11)
/RX: J1.8 (GPIO14/TXD), U3.2 (GPIO1)
/SHUTDOWN: U3.26 (GPIO20); also elsewhere on the board
/TX: J1.10 (GPIO15/RXD), U3.1 (GPIO0)
Earth: C101.2, C102.2, J2.1
GND: C3.2, C6.1, C7.2, C111.1, C112.1, C113.2, D1.1 (K), D3.2 (A2), D5.2 (A2), D104.1 (K), D105.2 (A2), D106.2 (A2), D107.1 (K), J1.6 (GND), J1.9 (GND), J1.14 (GND), J1.20 (GND), J1.25 (GND), J1.30 (GND), J1.34 (GND), J1.39 (GND), R4.2, R7.1, R8.1, R10.2, R12.2, R19.2, SW1.2, U1.2 (A), U3.3 (GND), U3.8 (GND), U3.13 (GND), U3.18 (GND), U3.23 (GND), U3.28 (GND), U3.33 (AGND), U3.38 (GND), U3.42 (GND), U103.7 (GND); also elsewhere on the board
unnamed: C1.1, C102.1, C109.1, D2.2, L2.1, L104.2
unnamed: C1.2, R5.2
unnamed: C2.2, R6.2
unnamed: C4.1, R3.2, R4.1, R14.1, U103.4 (IN-)
unnamed: C4.2, D5.1 (A1), R6.1, R9.2, R10.1, R14.2, R17.2, U103.5 (VO1)
unnamed: C5.2, Q1.3 (D)
unnamed: C6.2, D2.3 (-), D6.2 (A2), Q1.2 (S), R15.1
unnamed: C7.1, L1.2, R109.1, R114.1
unnamed: C8.1, R18.2, R19.1, R104.2, R108.1
unnamed: C8.2, R3.1
unnamed: C2.1, C101.1, C110.1, D2.4, L2.4, L105.2
unnamed: C109.2, R101.2
unnamed: C110.2, R102.2
unnamed: C113.1, U103.2 (BYPASS), U103.3 (IN+)
unnamed: D1.2 (A), R1.2
unnamed: D2.1 (+), R16.2
unnamed: D3.1 (A1), R5.1, R11.2, R12.1, R17.1, U103.8 (VO2)
unnamed: D6.1 (A1), Q1.1 (G), R15.2, R16.1
unnamed: D101.1 (A1), J2.3, L2.2, L104.1
unnamed: D101.2 (A2), J2.2, L2.3, L105.1
unnamed: D104.2 (A), R103.2
unnamed: D105.1 (A1), R102.1, R110.2, R114.2
unnamed: D106.1 (A1), R101.1, R109.2, R116.2
unnamed: D107.2 (A), R107.2
unnamed 45: R2.2, U103.1 (SHUTDOWN); also elsewhere on the board
unnamed: SW1.1, U3.30 (RUN)

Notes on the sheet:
P1/P2 bus
bus power detection
TS4990 drives 1.1W@5.0V
DNP
UART
Transmitter and receiver are AC coupled to detect bus collisions
C4: Low pass filter for less overshoot/undershoot
input impedance >10kOhms
Vout 0,3 - 4,7V Differential amplitude: +-4,4V Pout: 3W max 4.5 Ohms output impedance
low Vf diode
low pass filter 16x oversampling at 9600baud
Reset button
Flow control
Limit Vin to -0,6V to 5,6V
Transmitter
echonet specification: Input impedance: >10kOhms Output impedance: <40 Ohms Receiving levels: High 1.4V, Low 0.6V
Charge cap to test if bus voltage is present
3000mV precision shunt
2,5V bias >10kOhms input impedance
Enable shutdown while receiving to reduce power consumption Tristate drive A_H and A_L to transmit AMI code
Vadc: 0-3.0V
LM4871 is the replacement part for TS4990
Receiver

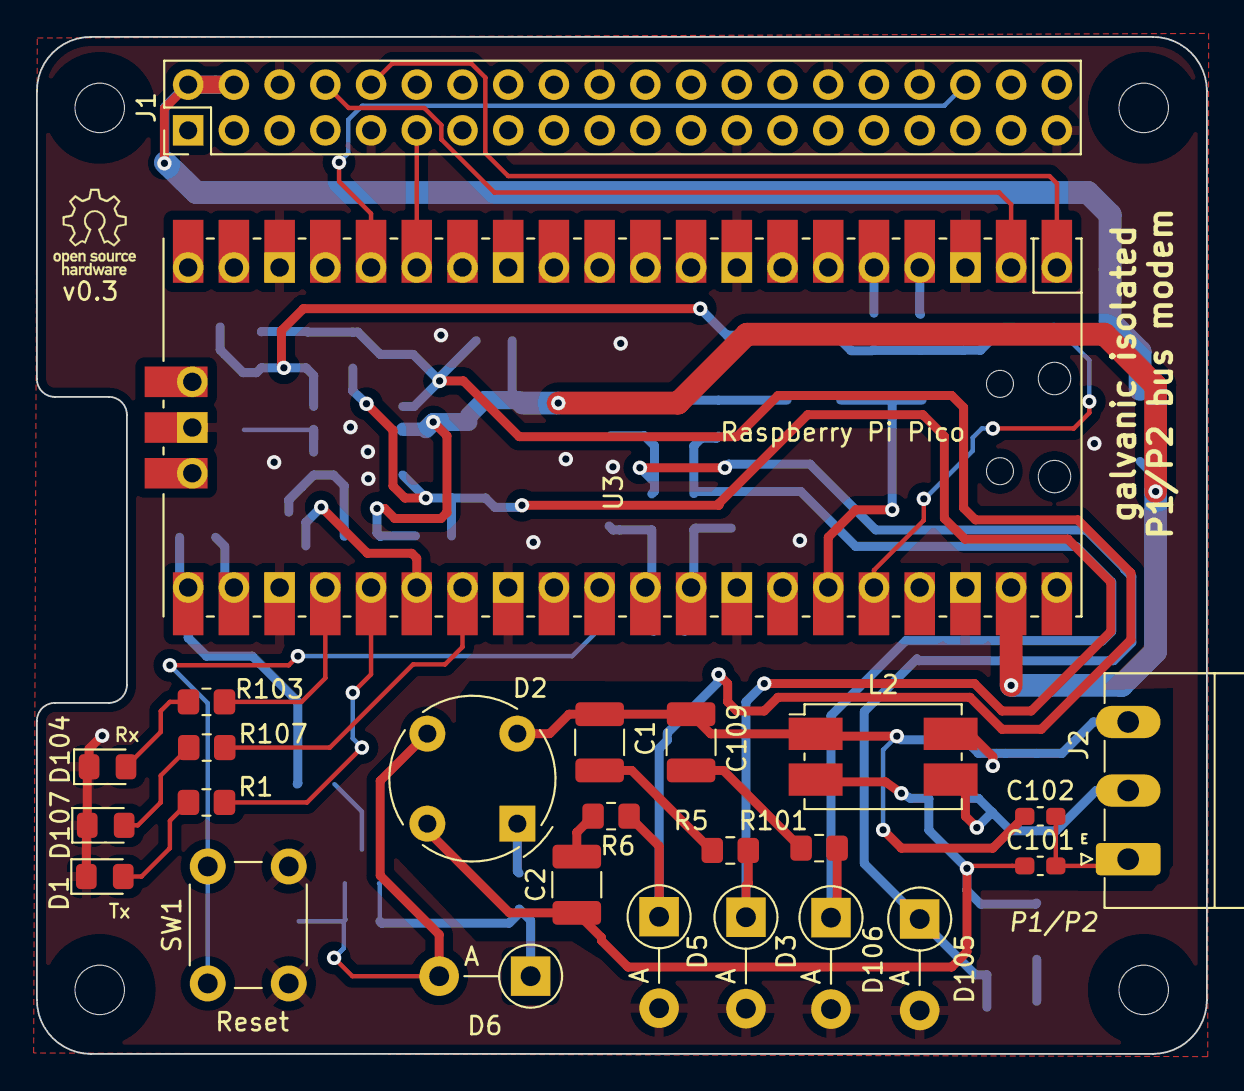
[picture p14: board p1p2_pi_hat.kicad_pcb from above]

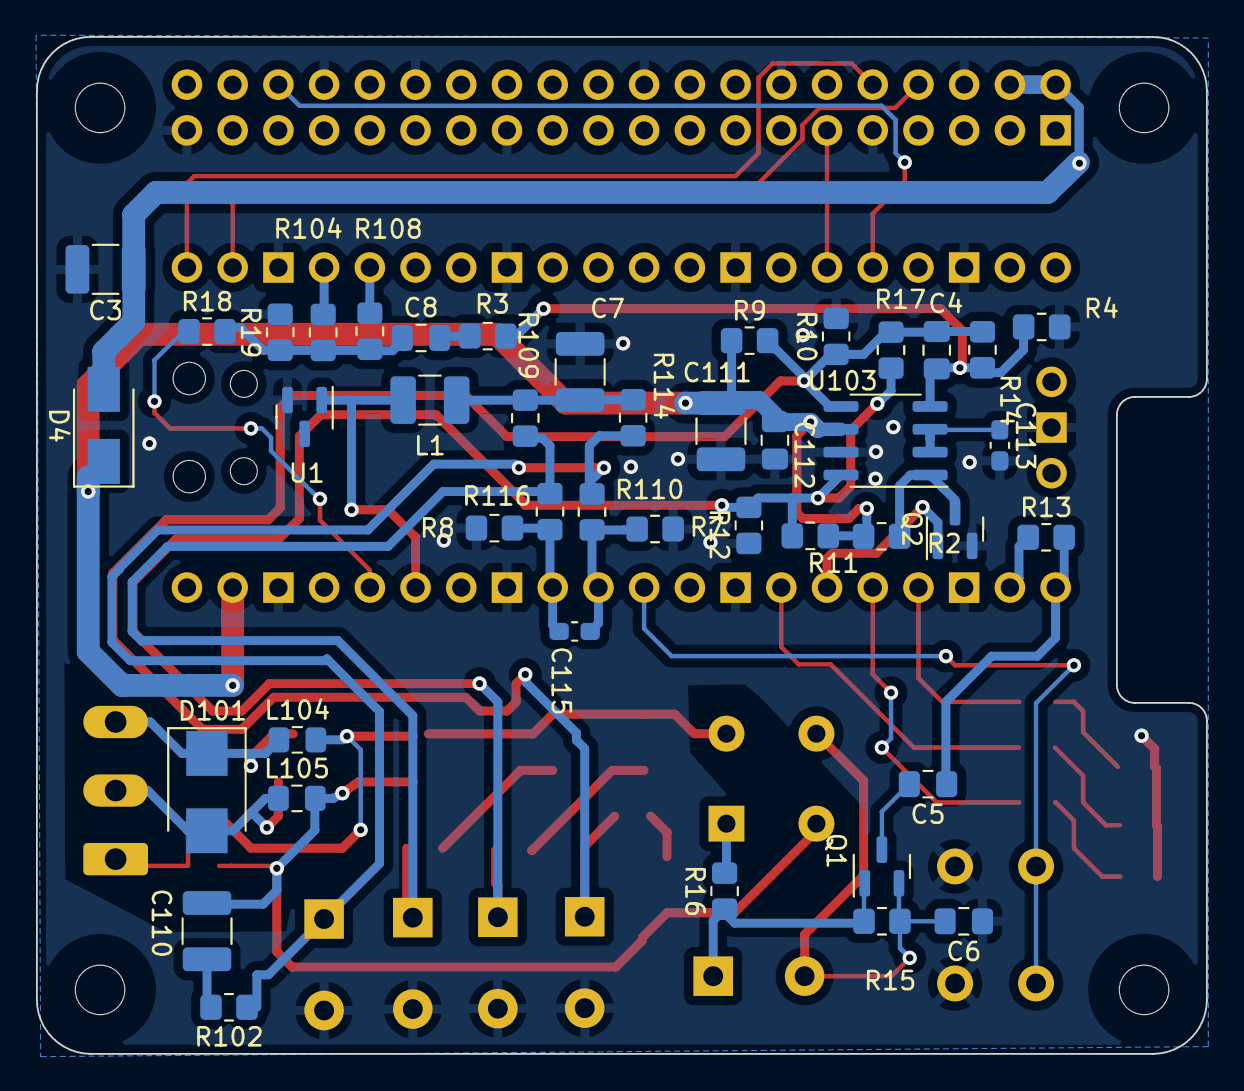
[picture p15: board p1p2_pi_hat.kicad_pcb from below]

Board: 2 copper layers, 65.0 x 56.5 mm, 68 parts (43 on the bottom side), 46 nets.

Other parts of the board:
Q2: BSS123; SOT-23

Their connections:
/SHUTDOWN: Q2.1 (G); also elsewhere on the board
GND: Q2.2 (S); also elsewhere on the board
unnamed 45: Q2.3 (D); also elsewhere on the board

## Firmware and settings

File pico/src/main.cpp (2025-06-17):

#include <stdio.h>
#include <pico.h>
#include <pico/stdlib.h>
#include <pico/multicore.h>

#include <hardware/sync.h>

#include "adc.hpp"
#include "adc_sw.hpp"
#include "uart.hpp"
#include "fir_filter.hpp"
#include "resample.hpp"
#include "uart_pio.hpp"
#include "led_driver.hpp"
#include "host_uart.hpp"
#include "dcblock.hpp"
#include "led_manager.hpp"
#include "level_detect.hpp"
#include "uart_bit_detect_fast.hpp"
#include "standalone.hpp"
#include "tx_statemachine.hpp"

//
// Global signal processing blocks
//

#ifdef USE_SW_ADC
__scratch_x("ADCInstance") uint16_t adc_data[0x100] __attribute__ ((aligned(0x200)));
DifferentialADC_SW& dadc = DifferentialADC_SW::getInstance(adc_data);
#else
// DifferentialADC provides the differential AC voltage signal captured from
// the P1P2 lines. As the RP2040 has no differential ADC hardware, the
// signal is delayed by 2 ADC samples to emulate a phase correct differential
// capture.
// Provides an 16x oversampled signal.
__scratch_x("ADCInstance") int16_t adc_data[0x100] __attribute__ ((aligned(0x200)));
DifferentialADC& dadc = DifferentialADC::getInstance(adc_data);
#endif

// filter implements a FIR filter to reduce high frequency noise
// captured by the ADC. As the FIR filter is processing intense,
// the length was set to 7.
// Introduces a delay of about 4 ADC samples.
__scratch_x("FIRFilter1") int32_t fir_data1[7 * 2];
__scratch_x("FIRFilter2") int32_t fir_data2[7 * 2];
FIRFilter filter(fir_data1, fir_data2);

#if (FIR_OVERSAMPLING_RATE / UART_OVERSAMPLING_RATE) == 4
// resampler drops 3 samples out of 4 as it's not needed any more after
// FIR filtering the signal.
// Provides an 8x oversampled signal.
Resample<int32_t> resampler(3);
#else
#if (FIR_OVERSAMPLING_RATE / UART_OVERSAMPLING_RATE) == 2
// resampler drops 1 samples out of 2 as it's not needed any more after
// FIR filtering the signal.
// Provides an 8x oversampled signal.
Resample<int32_t> resampler(1);
#else
#error Unsupported FIR_OVERSAMPLING_RATE to UART_OVERSAMPLING_RATE ratio!
#endif
#endif

// dcblock removes the DC level by using about 200 samples. DC offsets can
// appear when the used resistors have a high tolerance and don't properly
// match each others value.
DCblock dcblock;

// p1p2uart decodes the P1P2 data signal to bytes. It can detect parity errors, frame
// errors and DC errors ("0" not encoded as alternating up/down).
__scratch_x("UART") int16_t uart_data[UART_BUFFER_LEN * 2];
UART p1p2uart(uart_data, UART::PARITY_EVEN);

// Level applies the P1P2 bus hysteresis.
// The low level signal amplitude is reduced to 0.1.
// The high level signal amplitude is unchanged.
Level<int32_t> level;

// bit returns the probabilty for a high or low pulse found in the signal.
// Allow 0xE0/0x100 bit errors = 12,5%
__scratch_x("UARTBit1") int32_t uart_bit_data[UART_OVERSAMPLING_RATE * 2];
__scratch_x("UARTBit2") int32_t uart_bit_data2[UART_OVERSAMPLING_RATE * 2];
UARTBit<int32_t, UART_OVERSAMPLING_RATE> bit(uart_bit_data, uart_bit_data2, BUS_HIGH_MV, BUS_LOW_MV, 0xE0);

// uart_tx implements the P1P2 transmitting part. The caller must avoid bus collisions on
// the half duplex P1P2 bus. uart_tx has an internal 64 byte software fifo.
__scratch_y("UART") UARTPio& uart_tx = UARTPio::getInstance();

// HostUART implement the logic to interface with the host
// It generates and decodes the messages transceived on the host interfaces.
// It updates the status bits on internal error.
__scratch_y("host_uart") HostUART& hostUart = HostUART::getInstance();

// LED drivers
__scratch_y("pled") LEDdriver PowerLED = LEDdriver(21);
__scratch_y("tled") LEDdriver TxLED = LEDdriver(19);
__scratch_y("rled") LEDdriver RxLED = LEDdriver(18);

// The LED manager drives various patterns on the LEDs depending on the current
// system state.
__scratch_y("ledmanager") LEDManager LedManager(RxLED, TxLED, PowerLED);

__scratch_y("standalone") StandaloneController ctrl;

struct csv {
	int16_t sample;
	uint8_t flags;
	int16_t adca;
	int16_t adcb;
};

union CoreInterchangeData {
	struct {
		uint8_t RxChar;
		uint8_t RxValid : 1;
		uint8_t RxError : 1;
		uint8_t LineBusy : 1;
		uint8_t LineFree : 1;
		uint8_t DADCError : 1;
	};
	uint32_t Raw;
};

// Data exchange variables. Unidirectional only.
volatile bool FifoErr;

static void core1_entry() {
	uint8_t rx_data;
	bool rx_error;
	int32_t adc_data, fir_data, resamp_data, ac_data, hysteresis_data, bit_data;
	int32_t LineIdleCounter;
	bool LineIsBusy;

	CoreInterchangeData Core1Data;

	FifoErr = false;
	LineIsBusy = true;
	Core1Data.Raw = 0;
	LineIdleCounter = 11 * UART_OVERSAMPLING_RATE;

	dadc.SetGain((uint16_t)(ADC_EXTERNAL_GAIN * 0x100));
	dadc.Start();
	for (;;) {
		if (Core1Data.Raw) {
			if (!multicore_fifo_wready()) {
				FifoErr = true;
			} else {
				multicore_fifo_push_timeout_us(Core1Data.Raw, 0);
			}
			Core1Data.Raw = 0;
		}
		if(!dadc.Update(&adc_data)) {
			__wfe();
			continue;
		}
		if (dadc.Error ()) {
			Core1Data.DADCError = true;
			dadc.Reset();
			continue;
		}
		if (!filter.Update(adc_data, &fir_data)) {
			continue;
		}
		if (!resampler.Update(fir_data, &resamp_data)) {
			continue;
		}

		if (!dcblock.Update(resamp_data, &ac_data)) {
			continue;
		}
		if (!level.Update(ac_data, &hysteresis_data)) {
			continue;
		}

		bit.Update(hysteresis_data, &bit_data);

		// p1p2uart is busy as long as receiving a byte. It has an
		// idle phase of UART_OVERSAMPLING_RATE/2 or less between two bytes.
		// Thus the line is idle when p1p2uart haven't signaled busy for
		// at least UART_OVERSAMPLING_RATE samples.
		//
		// The idle time between packets on the P1/P2 bus is unknown.
		// Assume idle time of 1 byte == 9600Baud/11 bits == 1.15msec.

		if (p1p2uart.Receiving()) {
			if (!LineIsBusy) {
				LineIsBusy = true;
				LineIdleCounter = 11 * UART_OVERSAMPLING_RATE;
				Core1Data.LineBusy = 1;
			}
		} else if (LineIsBusy) {
			if (LineIdleCounter > 0) {
				LineIdleCounter--;
			} else {
				LineIsBusy = false;
				Core1Data.LineFree = 1;
			}
		}


		rx_data = 0;
		if (!p1p2uart.Update(bit_data, &rx_data, &rx_error)) {
			continue;
		}
		Core1Data.RxChar = rx_data;
		Core1Data.RxError = rx_error;
		Core1Data.RxValid = !rx_error;
	}
}

static void core0_entry() {
	Message RxMsg;
	bool LineIsBusy;
	bool TxFailure;
	uint32_t LineBusySinceMsec;
	CoreInterchangeData Core1Data;
	TxStateMachine SM(uart_tx);

	LineIsBusy = true;
	LineBusySinceMsec = to_ms_since_boot(get_absolute_time());

	// discard old data
	multicore_fifo_drain();

	while(1) {
		// USB CDC has no interrupts.
		// Poll for changes...
		hostUart.Check();

		ctrl.Check();

		TxFailure = SM.Error();

		// Update LEDs
		if (SM.IsTransmitting())
			LedManager.ActivityTx();
		else if (FifoErr || uart_tx.Error())
			LedManager.InternalError();
		else if (TxFailure)
			LedManager.TransmissionErrorTx();

		// Check if line is busy for too long.
		if (LineIsBusy) {
			if (LineBusySinceMsec + LINE_BUSY_TIMEOUT_MS < to_ms_since_boot(get_absolute_time())) {
				LedManager.InternalError();
				LineBusySinceMsec = to_ms_since_boot(get_absolute_time());
				RxMsg.Status = Message::STATUS_ERR_NO_FRAMING;
				hostUart.UpdateAndSend(RxMsg);
				RxMsg.Clear();
			}
		}

		// FIFO errors should never happen
		if (FifoErr) {
			RxMsg.Status = Message::STATUS_ERR_OVERFLOW;
			hostUart.UpdateAndSend(RxMsg);
			RxMsg.Clear();

			FifoErr = false;
		}

		// Failed to TX a packet. Notify HOST and CTRL.
		if (TxFailure) {
			if (SM.RxMsg.Status != Message::STATUS_ERR_PARITY) {
				// STATUS_ERR_PARITY is already send by RX code
				hostUart.UpdateAndSend(SM.RxMsg);
				SM.RxMsg.Clear();
			}
			if (ctrl.IsTxAnswer(&SM.TxMsg))
				ctrl.BusCollision();
		}

		// Handle CORE0 events
		if (multicore_fifo_rvalid()) {
			Core1Data.Raw = multicore_fifo_pop_blocking();

			// Update RxMsg
			if (Core1Data.DADCError)
				RxMsg.Status = Message::STATUS_ERR_OVERFLOW;
			else if (Core1Data.RxError) {
				RxMsg.Status = Message::STATUS_ERR_PARITY;
				RxMsg.Append(Core1Data.RxChar);
			} else if (Core1Data.RxValid)
				RxMsg.Append(Core1Data.RxChar);

			// Packet end reached, transmit now...
			if (Core1Data.LineFree) {
				if (RxMsg.Length > 0 || RxMsg.Status != 0) {
					// Update external controller
					ctrl.Receive(&RxMsg);

					// Send to host
					hostUart.UpdateAndSend(RxMsg);
					RxMsg.Clear();
				}
			}
			// Received more data than would fit into message...
			if (RxMsg.Overflow()) {
				RxMsg.Status = Message::STATUS_ERR_OVERFLOW;
				hostUart.UpdateAndSend(RxMsg);
				RxMsg.Clear();
			}

			// Update half duplex state machine
			if (Core1Data.LineFree && LineIsBusy) {
				LineIsBusy = false;
			} else if (Core1Data.LineBusy && !LineIsBusy) {
				LineIsBusy = true;
				LineBusySinceMsec = to_ms_since_boot(get_absolute_time());
			}

			// Update LEDs
			if (Core1Data.RxError) {
				LedManager.TransmissionErrorRx();
			} else if (Core1Data.RxValid) {
				LedManager.ActivityRx();
			}
			if (Core1Data.DADCError) {
				LedManager.InternalError();
			}

		} else if (LineIsBusy) {
			// Break every msec to check LineBusySinceMsec counter and statemachine
			best_effort_wfe_or_timeout(make_timeout_time_ms(1));
		} else if (!ctrl.HasTxData() && !hostUart.HasDataExtController() && !hostUart.HasDataGeneric() && SM.IsIdle()) {
			// Nothing to TX and statemachine is idle
			// Need to break every few msec to poll the USB CDC
			best_effort_wfe_or_timeout(make_timeout_time_ms(1));
			continue;
		}

		// Update half duplex statemachine
		SM.Update(LineIsBusy, Core1Data.RxError, Core1Data.RxValid, Core1Data.RxChar);

		Message TxMsg;
		// Relay messages for standalone controller
		// It will be transmitted when requested by the control unit
		if (hostUart.HasDataExtController()) {
			TxMsg = hostUart.PopExtController();
			ctrl.CacheTxMessage(TxMsg);
		}
		// Let standalone controller also handle non standalone packets!
		// It will send those packets instead of the "correct" answer packet
		// to avoid bus collissions.
		if (hostUart.HasDataGeneric() && !ctrl.Non3xhPacketWaitForTransmission()) {
			TxMsg = hostUart.PopGeneric();
			ctrl.CacheTxMessage(TxMsg);
		}
		// Transmit packet if any. Start transmission in the moment the lines becomes idle.
		if (SM.IsIdle() && ctrl.HasTxData()) {
			ctrl.TxAnswer(&TxMsg);
			SM.WakeAndTransmit(TxMsg);
		}

		Core1Data.Raw = 0;
	};
}

int main(void) {
	stdio_init_all();	// Must be called on core0!
	sleep_ms(3000);

	printf("\n#==================\n");
	printf("#RP2040 P1/P2 modem\n");
	printf("#==================\n");
	printf("# Send ;!BLD!; to enter USB bootloader\n");

	uart_default_tx_wait_blocking();

	multicore_launch_core1(core1_entry);

	core0_entry();
}

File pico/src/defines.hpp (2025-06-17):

// Sample rate settings

// Oversample the signal by 16 times
#define UART_OVERSAMPLING_RATE 16
// FIR filtered reduces samplerate by 0.5
#define FIR_OVERSAMPLING_RATE (UART_OVERSAMPLING_RATE * 2)
// ADC operates on the FIR filter input sample rate
#define ADC_OVERSAMPLING_RATE FIR_OVERSAMPLING_RATE

// P1P2 bus settings
#define UART_BAUD_RATE 9600
#define BUS_HIGH_MV 1400
#define BUS_LOW_MV 600

// ADC settings
#define ADC_REF_VOLTAGE_MV 3000
#define ADC_DMA_BUFFER_SIZE 256
#define ADC_EXTERNAL_GAIN 1.666

// TX power safe mode and high impedance mode in micro seconds
// The LM4871 has a startup time of 15 msec.
// The TS4990 has a startup time of 32 msec.
// The P1P2 Daikin bus has a minimum 25msec silence between packets.
// Tests showed that a minimum of 5msec is sufficient between packets.

#define TX_POWERON_TIMEOUT_US 32000
#define TX_ONE_CHAR_TIMEOUT_US 2000
#define TX_RX_TIMEOUT_US 2000

// Max line busy time in milli seconds
#define LINE_BUSY_TIMEOUT_MS 500

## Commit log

2021-09-04 Initial commit
    - Add schematics and PCB
    - Still WIP
    [p1p2_rs232_receiver.kicad_pcb, p1p2_rs232_receiver.sch]
2021-09-07 Update PCB
    - Increase dimension for easy DIN rail mounting
    - Add more labels
    - Move parts to increase ground plane
    [p1p2_rs232_receiver.kicad_pcb]
2021-09-07 Add 9600baud CTS low pass filter
    - Add low pass filter with tRC of 1.2 msec
    - Pull CTS low when data is received for easy collision detection
    [p1p2_rs232_receiver.kicad_pcb, p1p2_rs232_receiver.sch]
2021-09-18 Update PCB
    [p1p2_rs232_receiver.kicad_pcb]
2021-09-18 Add PDF/PNG showing 3D view, schematics and PCB
2021-09-22 pcb: Place Arduino on board
    Add an Arduino to the board and a connector for external microcontrollers.
    The HBS protocol requires AMI code to be transmitted, which cannot be easily
    be done in hardware due to clock recovery issues.
    [p1p2_rs232_receiver.kicad_pcb, p1p2_rs232_receiver.sch]
2021-10-01 Fix some issues
    - Fix Q101 pinout
    - Change 2k5 to 2k49 Ohm
    - Change 720 to 750 Ohm
    [p1p2_rs232_receiver.kicad_pcb, p1p2_rs232_receiver.sch]
2022-01-02 pcb: Convert to standalone AMI AFE
    [p1p2_rs232_receiver.kicad_pcb, p1p2_rs232_receiver.sch]
2022-06-03 kicad: Create a PI hat compatible P1/P2 modem
    Create a P1/P2 transceiver as Rapsberry PI hat using some
    analog components and a Raspberry PI Pico (RP2040).
    [p1p2_rs232_receiver.kicad_pcb, p1p2_rs232_receiver.kicad_sch]
2022-06-04 kicad: Minor fixes
    [p1p2_rs232_receiver.kicad_pcb, p1p2_rs232_receiver.kicad_sch]
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2022-09-06 Add RPI pico source code
    Use ADC, DMA, PIO0, PIO1 and lot's of optimised C++ to create a P1/P2 modem.
    TODO:
    - Host interface
    - Documentation
2022-11-05 kicad: Update schematics
    - Add common mode choke
    - Use gain 5 for OpAmp
    The OpAmp is not stable at unity gain.
    The OpAmp is not stable with high impedance load (unconnected P1/P2 bus).
    - Use OpAmp in inverting operation mode instead voltage follower mode
    - Add 'DNP' pull down and capacitor on OpAmp feedback
    TODO: Figure out if required for stability.
    - Replace DC bus level detection
    - Use external precision 3.0V voltage shunt as ADC voltage
    - Use 3.0V as bias voltage to reduce noise
    - Add Pico reset button
    [p1p2_rs232_receiver.kicad_pcb, p1p2_rs232_receiver.kicad_sch]
2022-11-05 uart_pio: Return error on FIFO overrun
    [uart_pio.cpp]
2022-11-05 twos_complement: Add IRQ support
    Trigger an IRQ when FIFO is not empty. This allows to use __wfe().
    The DMA channel would be a even better, but it does not trigger an
    IRQ on finished transfer chunk.
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2022-11-05 level_detect: Add hysteresis and reduce signal level on line idle
    This improves the signal quality as the AC coupling introduces distortions.
2022-11-05 uart: Move probabilty decision into uart_bit_detect
    Move the decision if a symbol is +1, -1 or idle to uart_bit_detect.
2022-11-05 defines.hpp: Add define for external resistor divider
    Introduce ADC_EXTERNAL_GAIN to compensate external resistor divider.
    Remove hardcoded value from main.
2022-11-05 src/uart: Move UARTbit to main
2022-11-05 src/uart: Use only one shift register
2022-11-05 kicad: Update schematic
    [p1p2_rs232_receiver.kicad_pcb, p1p2_rs232_receiver.kicad_sch]
2022-11-05 uart_pio: Add support for sending messages
2022-11-05 uart: Fix spacing
2022-11-05 main: Multiple fixes
    - Implement TX state machine
    Block the transmission of packets until the line is free.
    - Use STDIO methods to transceive data over UART0 and USB CDC.
    - Fix Message c_str function
    [host_uart.cpp, main.cpp]
2022-11-05 src/adc: Drop hardware/interp
    It's unused.
2022-11-05 pico: Add missing LED manager header
2022-11-06 pico: Add missing header
2022-11-06 pico/src: Drop gain
    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
2022-11-06 pico/src: Drop channel_comp
    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
2022-11-06 pico/tests/uart_bit_detect: Fix unit test
    [uart_bit_detect_test.cpp]
2022-11-06 pico/src/main: Move printf and sleep to core0
    This fixes core0 not being able to send data to core1 for
    3 seconds.
    [main.cpp]
2022-11-06 pico/src/main: Clear Core1Data on error path as well
    [main.cpp]
2022-11-06 pico/src/main: Drain fifo on core1 entry
2022-11-06 pico/src/main: Put LM4861 into sleep
    Drive the lines only when transmitting.
2022-11-06 pico/src: Remove unused variable
2022-11-06 pico/tests: Fix message unit tests
2022-11-20 main: Switch core0 and core1
    stdio_init_all() must be called on core0.
    Move UART handling code to core0 and ADC code to core1.
2022-11-23 pico: Replace IRQ fifo
    Drop circular_buffer_spinlock and line_receiver and replace
    it with an IRQ safe FIFO. As data doesn't need to be transfered
    between cores, there's no need for a spinlock.
    [host_uart.cpp, main.cpp, uart_pio.cpp]
2022-11-26 main: Update TX handling
    - Add timeout for TX buffer enables (15 milliseconds)
    - Add line busy timeout
    - Enable WFE with timeout
    - Disable TX buffer by default to make line high impedance
2022-11-26 main: Signal TransmissionErrorTx using LEDmanager
2022-11-27 Documentation: Add LED chapter
2022-11-27 kicad: Add warning texts to design
    [p1p2_rs232_receiver.kicad_sch]
2022-12-17 doc: Explain RPi3 UART0 pitfalls
2022-12-31 pico/src/adc: Fix DMA block IRQ handler
    Need to reset the write address register, as it's not the start
    address register, but the actual target write address register
    incrementing on each transfer.
    Clear the DMA IRQ and don't reset DMA inside the IRQ handler.
    Move resetting the DMA to Update() method to prevent race conditions
    with IRQ handler.
    [adc.cpp]
2023-01-04 pico/src/uart_pio: Add more comments
2023-01-04 src/uart_pio: Fix SW to HW FIFO IRQ handler
    Prevent race conditions filling the HW FIFO.
    Only fill the SW FIFO and let the IRQ handler fill
    the HW FIFO to prevent glitches when HW FIFO has
    been filled with 8 bytes.
    [uart_pio.cpp]
2023-01-04 pico/src: Add Daikin external controller emulation
    Answer request on address 0xF0 to emulate Daikin external
    controller. Scan the bus to prevent address collisions
    with existing controllers on 0xF0 or 0xF1.
    Tested using Daiking P1P2 bus. The main controller is able
    to see the response and adds additional packets on the bus.
    [defines.hpp, main.cpp]
2023-01-06 pico: Update uart documentation
2023-01-07 Update Readme.md: Add build instruction
    Explain how to build the Pico source code.
2023-01-07 pico/tests: Make FIR filter less verbose
    Remove verbose prints and check frequency response.
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2023-01-09 pico/src/standalone: Answer packet 00f031
    Anser the request and return the expected DeviceID.
    This fixes 'installer mode' cannot be entered on the control unit.
2023-01-09 pico/src/main: Send PIO overrun to host
    Do not only blink the LED but also send the PIO overrun to the
    host and flush the queue.
2023-01-09 pico/src/host_uart: Allow to enter USB bootloader
    On received string ";!BLD!;" enter the USB bootloader.
2023-01-10 pico: Add line_receiver_irqsafe
    For host uart receival add line_receiver_irqsafe as new
    class. Optimize fifo_irqsafe to be faster, but incompatible
    with host uart receival.
    [host_uart.cpp]
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2023-01-10 pico/src/uart_pio: Use DMA instead of IRQ
    Replace software FIFO with IRQ support with DMA fifo.
    Reduces CPU load on transmitting data using UART PIO.
    [uart_pio.cpp]
2023-01-10 pico/src/main: Handle more errors in TX state machine
    [main.cpp]
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2023-01-21 kicad: Update schematics
    [p1p2_rs232_receiver.kicad_sch]
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2023-01-21 pico/src/host_uart: Improve string parsing
    - Ignore messages with no data.
    - Don't parse messages starting with CR or LF
2023-01-21 kicad/doc: Update documentation
    - Recommend LM4871 instead LM4861
    - Add experimental results
2023-04-02 kicad: Redesign to TX with more power
    - Use 5V as LM4871 power supply
    - Decrease output impedance to 4.5 Ohms
    - Decrease input impedance to 1k Ohm
    - AC couple input signal
    [p1p2_rs232_receiver.kicad_pcb, p1p2_rs232_receiver.kicad_sch]
2023-07-03 kicad: Fixes for version v0.3
    - Replace Ti LM4871 with STM TS4990
    - Power SHUTDOWN from +5V rail
    - Use double ground plane
    [p1p2_rs232_receiver.kicad_pcb, p1p2_rs232_receiver.kicad_sch]
2023-08-25 pico/main: Move state machine to seperate files
    Move the TX/half duplex state machine out of main.cpp
2023-08-25 pico/defines: TS4990 has longer startup time
    TS4990 has a startup time of 32 msec.
2023-08-25 pico/main: On RxError add received char to message
    Add all received characters to RxMessage.
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2023-08-25 pico: Fix shutdown level
    Since v0.3 the shutdown polarity is inverted.
    [uart_pio.cpp]
2023-08-26 kicad/doc: Add startup time
    Add startup time of STM TS4990.
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2024-10-02 kicad: Rename kicad files
    [p1p2_pi_hat.kicad_pcb, p1p2_pi_hat.kicad_sch, p1p2_pi_hat.sch]
2024-10-02 kicad: use DNP flag
    [p1p2_pi_hat.kicad_sch]
2025-05-17 pico: Bump pico-sdk to 2.1.0
    Adapt the code to compile with new SDK.
2025-05-17 uart_bit_detect_fast: Fix typo
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2025-05-17 shiftreg.hpp: Generate smaller code
    Optimize the code to generate less assembly instructions.
2025-05-17 uart_bit_detect_fast.hpp: Fix comment
    The function returns void, so fix the comment.
2025-05-18 tests: Add missing files for tx_statemachine_test
    Mock the PIO and the timebase.
    [tx_statemachine_test.cpp]
2025-05-18 src: Add adc_sw
    Add software implementation of differential ADC. Uses IRQ
    safe FIFO and interrupts instead of DMA + PIO + DMA.
2025-05-18 adc: Fix IRQ registered on wrong core
    This caused the core to not wake often enough causing a buffer underflow.
    That in turn causes peaks in the signal as the inverting and non-inverting
    channel might get flipped.
    Now the the correct core registers the IRQ handler the correct core is also
    woken up on IRQ and can process the data.
    [adc.cpp]
2025-05-18 main: Use DMA differential ADC
    The IRQ based solution isn't fast enough for 16x oversampling.
    Use the DMA based differential ADC, it's faster.
2025-05-18 doc: Update UART
    Describe new format being used.
2025-06-06 standalone: Request handling of 0x3xh packets
    In the response of 30h packets acknowledge which other 3xh packets
    are currently pending and require transmission.
2025-06-15 pico: Improvements around TX packets
    - Always answer 3xh packets. This reduce the time spent waiting
    for the next 3xh packet.
    - Improve host uart parsing
    - Transmit regular packets at the end of 3xh packet phase, by appending
    it to the statemachine when the output driver is still active.
    This allows to send the packet earlier (no need to wait for the output
    driver to enable), and it prevents bus collisions.
    Tests showed that 5msec is sufficient between two packets.
    As downside sending packets is now limited to one packet per 3xh
    parameter exchange. Thus one custom packet every 3 seconds can be transmitted.
    [defines.hpp, host_uart.cpp, main.cpp]
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2025-06-17 pico/src: Revert packet transmission after 3xh packet exchange
    Tests showed that the P1P2 control unit doesn't monitor the bus and
    starts transmitting after a fixed time period. This leads to bus
    collisions.
    Work around this send packets instead of the "correct" answer to a
    3xh packet request. The remote waits up to 180msec for the "correct"
    answer to be received, giving enough free bus time to transmit a packet
    and receive a response.
    Tests also showed that 5msec between packets is sufficient, maybe even
    less silence on the bus is okay.
    [defines.hpp, main.cpp]
